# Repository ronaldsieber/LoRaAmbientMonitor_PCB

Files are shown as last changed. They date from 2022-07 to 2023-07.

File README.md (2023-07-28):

# LoRaAmbientMonitor_PCB

**KiCad project of a Printed Circuit Board (PCB) for the LoRa-AmbientMonitor, based on ESP32 with temperature, humidity, PIR motion and ambient light sensor, as well as car battery voltage measurement.**

The *LoRa-AmbientMonitor* is designed to monitor the ambient conditions inside a car garage and also to monitor the voltage of the car battery. The acquisited data are transmitted to a remote station (e.g. in the house) via LoRa radio (low-power/long-range radio protocol).

## Board Features

The *LoRa-AmbientMonitor* contains the following components:
- ESP32 LoRa Development Board with OLED display
- DHT22 (combined temperature and humidity sensor)
- ALS-PDIC243 (Ambient Light Sensor)
- HC-SR501 (PIR Motion Detector)
- 3 freely usable user LEDs
- 4-position DIP switch and 1 freely usable user button (CFG, SET)
- 12V input to measure car battery voltage

The measurement of the ambient brightness via the ALS-PDIC243 Ambient Light Sensor as well as measurement of the car battery voltage is realized via 2 inputs of the Adafruit_ADS1115 module (4 channel 15-bit ADC module).

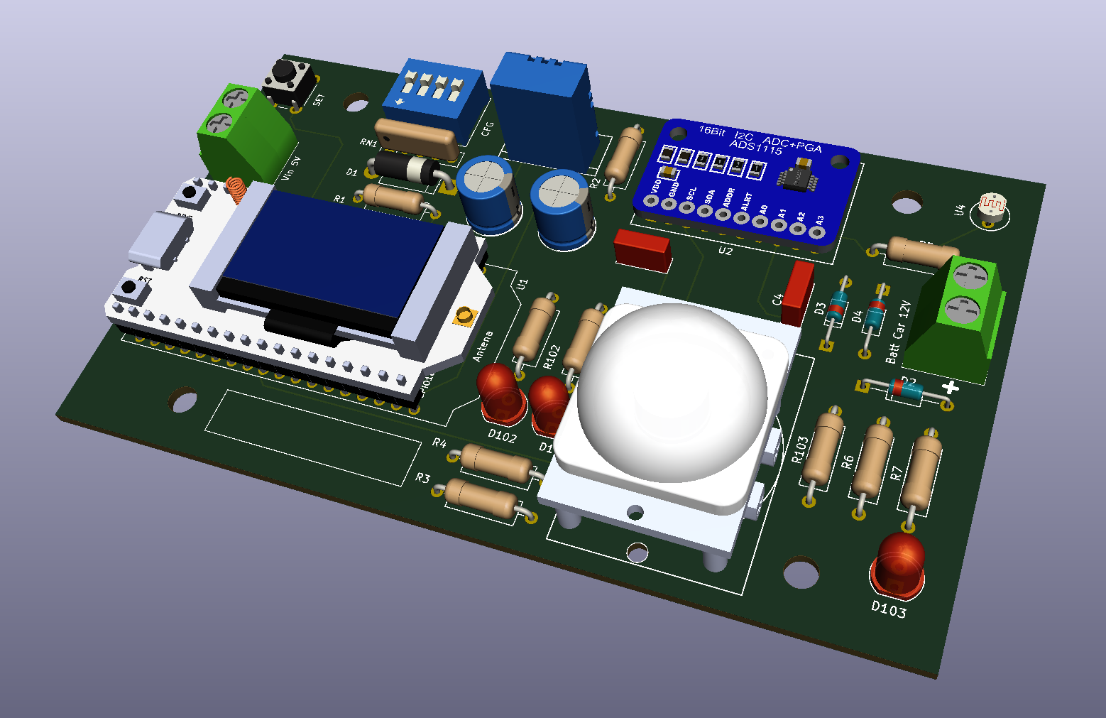
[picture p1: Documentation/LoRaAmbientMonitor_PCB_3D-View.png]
\[kicad_3d_model\]


## Board Description

The PCB of the *LoRa-AmbientMonitor* is a two-layer Printed Circuit Board (PCB), assembled on one side and only uses THT components (Through Hole Technology) that are very easy to solder. It can therefore be used very easily also by students and hobbyists.

The values of all components are specified in the [Schematic](Documentation/LoRaAmbientMonitor_PCB.sch.pdf). The [Silkscreen](Documentation/LoRaAmbientMonitor_PCB_Components.pdf) illustrates the placement of the components on the PCB.

The PCB size and the positions of the mounting holes allow installation in the plastic universal housing of 135 x 95 x 45 mm (article number 523117). Only the lower half-shell of the housing is used, so that the sensors (in particular the PIR motion detector HC-SR501 and the ambient light sensor ALS-PDIC243) can monitor the environment. Since the upper and lower half-shells are identical, the second half shell can be used for another *LoRa-AmbientMonitor*.

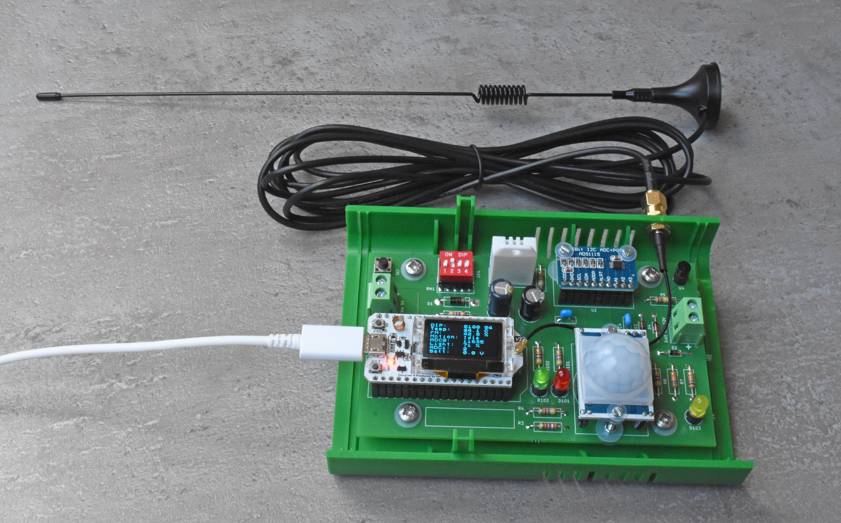
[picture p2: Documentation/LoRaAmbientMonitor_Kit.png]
\[LoRaAmbientMonitor_Kit\]


The user LEDs are connected to the GPIO of the ESP32 and can therefore be used freely in principle. However, the placement on the PCB was done in such a way that the following usage is favored:

 - LED D101, Red: Motion detected by PIR motion detector (HC-SR501).
 - LED D102, Green: Transmission of a LoRa data package
 - LED D103, yellow: connected car battery detected (e.g. Vin at J2 > 2V)

The 4-way DIP switch SW2 is also connected to the GPIO of the ESP32. It can be used for configuration settings at runtime. This makes it possible to program one and the same fixed firmware on several boards. Individual Node IDs can then be configured via the DIP switch. This individual Node IDs can be embedded in the LoRa data packets and thus enable the receiver to identify the correspondenting source module.

The User Button SW1 is also connected to the GPIO of the ESP32. It can be used freely by the application software and is suitable, among other things, as a starting condition for the [Bluetooth Configuration Framework](https://github.com/ronaldsieber/ESP32BleConfig).

The diodes D2, D3 and D4 serve as protection circuit for the ADC module ADS1115:
- D2: Reverse polarity protection for car battery measuring input
- D3: Overvoltage protection for car battery measuring input
- D4: Derivation of the car battery input voltage for a powerless ADS1115 (prevention of substrate conduction effects when a car battery is connected to a LoRa AmbientMonitor without power supply voltage)

## Power Supply

There are the following options for supplying power to the board:
- Via the USB port of the ESP32 LoRa Development Board (in this case, 'Pin2/5V' of the ESP32DevBoard acts as an output and supplies the rest of the circuit with it)
- Supply of 5...6VDC to connector J1 (in this case the board supplies the ESP32DevBoard and 'Pin2/5V' acts as an input)

## Commissioning

With the Arduino sketch from the [LoRaAmbientMonitor_IoCheck](https://github.com/ronaldsieber/LoRaAmbientMonitor_IoCheck) repository, all components of the board can be checked for correct function after assembly. The sketch is also a good starting point for new software projects based on this board.

## KiCad Schematic Symbols and Footprints

For the *LoRaAmbienteMonitor*, some schematic symbols and footprints have been newly created or modified. These are stored inside this repository in the [KiCad_Components/usrlib](KiCad_Components/usrlib) path.

The following KiCad library is also required for the combined temperature and humidity sensor DHT22:
https://github.com/skorokithakis/kicad-lib

## PCB Source of Supply

By searching in the Internet, several PCB manufacturers can be found who are able to directly import the KiCad layout file [LoRaAmbientMonitor_PCB.kicad_pcb](LoRaAmbientMonitor_PCB/LoRaAmbientMonitor_PCB.kicad_pcb). The PCBs with silkscreen (assembly printing) on the top are then sent by post after a few days.

## Practice Notes

On the PIR Motion Setector (U3, HC-SR501) are assembled larger/higher components such as trimmer potentiometers and electrolytic capacitors on its underside. Therefore, a 3-pin socket strip must be used on the PCB to ensure the required distance between the HC-SR501 and the PCB.

On the ESP32 LoRa Development Board (U1) there is a LiPo battery charger for 3.7V Lipo batteries is integrated. Due to the height of the JST 1.25mm battery connector on the underside of the board, the ESP32 LoRa Development Board cannot be soldered directly with its pin headers to the PCB of the *LoRaAmbienteMonitor*. Here, too, the required installation space can be created by using socket strips. Since the ESP32 LoRa Development Board has 18 pins per side, two 9-pin socket strips were used.

The 4-channel 15-bit ADC module (U2, Adafruit_ADS1115 module) is only equipped on its top side and can in principle be soldered directly to the PCB of the *LoRaAmbienteMonitor* with its pin headers. But here, too, the use of a 10-pin socket strip is a good idea, so that the module can be easily replaced if necessary.

## Software Projects for the LoRaAmbienteMonitor

- [LoRaAmbientMonitor_IoCheck](https://github.com/ronaldsieber/LoRaAmbientMonitor_IoCheck) - Checking of all components during commissioning and starting point for new software projects based on this board

- [LoraAmbientMonitor](https://github.com/ronaldsieber/LoraAmbientMonitor) - Complete software ecosystem for the *LoRaAmbienteMonitor* module, consisting of ESP32/Arduino firmware (transmitting side), Raspberry Pi gateway software (receiving and processing ambient data) and Windows/GUI commissioning tool.

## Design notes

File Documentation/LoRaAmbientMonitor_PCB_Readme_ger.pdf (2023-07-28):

Projekt: | https://github.com/ronaldsieber/LoRaAmbientMonitor_PCB
Lizenz: | MIT
Autor: | Ronald Sieber

## LoRaAmbientMonitor_PCB

KiCad Projekt des Printed Cuircit Boards (PCB) für den LoRa-AmbientMonitor auf ESP32-Basis mit Temperatur-, Luftfeuchtigkeits-, PIR-Bewegungs- und Umgebungslicht-Sensor, sowie Autobatterie-Spannungsmessung.

Der LoRa-AmbientMonitor ist dafür ausgelegt, die Umgebungsbedingungen innerhalb einer PKW-Garage zu monitoren und zusätzlich die Spannung der Autobatterie zu überwachen. Die erfassten Daten werden per LoRa-Funk (Low-Power/Long-Range Funkprotokoll) an eine entfernte Gegenstelle (z.B. im Wohnhaus) übertragen.

Board Features

Der LoRa-AmbientMonitor beinhalte folgende Komponenten:
- ESP32 LoRa Development Board mit OLED-Display
- DHT22 (kombinierter Temperatur- und Luftfeuchte-Sensor)
- ALS-PDIC243 (Ambient Light Sensor)
- HC-SR501 (PIR-Bewegungsmelder)
- 3 frei verwendbare User LEDs
- 4-fach DIP-Schalter und 1 frei verwendbare User Buttons (CFG, SET)
- 12V Eingang zur Messung der Autobatteriespannung

Die Messung der Umgebungshelligkeit über den ALS-PDIC243 Ambient Light Sensor sowie die Messung Autobatteriespannung erfolgen über 2 Eingänge des Adafruit_ADS1115 Moduls (4-fach 15Bit ADC-Modul).

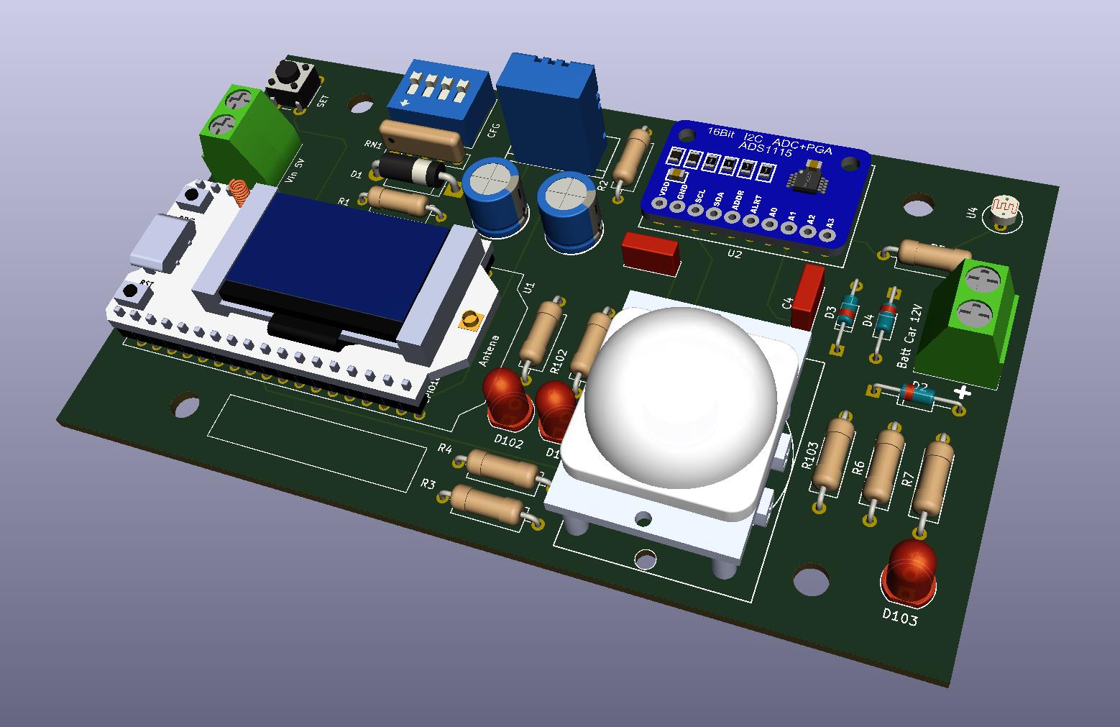
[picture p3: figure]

[kicad_3d_model]

Board Beschreibung

Die PCB des LoRa-AmbientMonitor ist eine zweilagige Leiterplatte, einseitig bestückt und verwendet nur sehr einfach zu lötende THT Bauteile (Through Hole Technology). Es kann somit sehr leicht auch von Schülern und Bastlern genutzt werden.

Die Werte aller Bauteile sind im <Schaltplan> spezifiziert. Die Platzierung der Bauteile auf der PCB veranschaulicht der <Bestückungsdruck>

Die PCB Größe und die Positionen der Mounting Holes erlauben den Einbau in das Kunststoff Universal Gehäuse von 135 x 95 x 45 mm (Artikel Nummer 523117). Vom Gehäuse wird dabei nur die Unterschale verwendet, so dass die Sensoren (insbesondere der PIR-Bewegungsmelder HC-SR501 und der Ambient Light Sensor ALS-PDIC243) die Umgebung überwachen können. Da Ober- und Unterschale identisch sind, kann die zweite Halbschale für einen weiteren LoRa-AmbientMonitor verwendet werden.

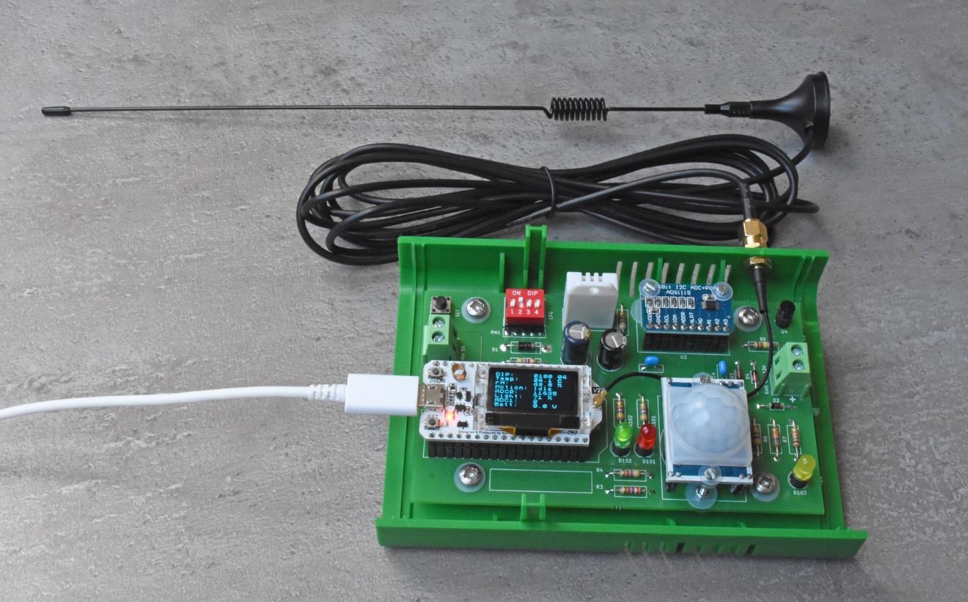
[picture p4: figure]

[LoRaAmbientMonitor_Kit]

Die User LEDs sind an GPIO des ESP32 angebunden und damit prinzipiell frei nutzbar. Die Platzierung auf der PCB erfolgte jedoch so, dass folgende Verwendung favorisiert wird:
- LED D101, Rot: Bewegung durch PIR-Bewegungsmelder (HC-SR501) erkannt
- LED D102, Grün: Übertragung eines LoRa Datenpaketes
- LED D103, Gelb: angeschlossene Autobatterie erkannt (z.B. Vin an J2 > 2V)

Der 4-fach DIP-Schalter SW2 ist ebenfalls an GPIO des ESP32 angebunden. Mit ihm können Konfigurationseinstellungen zur Laufzeit vorgenommen werden. So ist es möglich, eine feste Firmware auf mehrere Boards zu programmieren. Über den DIP-Schalter lassen sich dann individuelle Node-ID’s konfigurieren, die in die LoRa Datenpakte eingebettet werden und so dem Empfänger die Identifikation der jeweiligen Quelle ermöglichen.

Der User Button SW1 ist ebenso an GPIO des ESP32 angebunden. Er kann von der Applikations-Software frei verwendet werden und eignet sich u.a. als Startbedingung für das
<Bluetooth Configuration Framework>.

Die Dioden D2, D3 und D4 dienen als Schutzbeschaltung für den ADC Baustein ADS1115:
- D2: Verpolungsschutz für Autobatterie Messeingang
- D3: Überspannungsschutz für Autobatterie Messeingang
- D4: Ableitung der Autobatterie Eingangsspannung bei spannungslosem ADS1115 (Verhinderung von Substratleiteffekten, wenn eine Autobatterie an einen LoRa-AmbientMonitor ohne Versorgungsspannung angeschlossen ist)

Spannungsversorgung

Für die Spannungsversorgung des Boards gibt es folgende Möglichkeiten:
- über den USB-Anschluss des ESP32 LoRa Development Board (in diesem Fall wirkt ‘Pin2/5V‘ des ESP32DevBoards als Ausgang und versorgt die restliche Schaltung mit)
- Einspeisung von 5…6VDC an Konnektor J1 (in diesem Fall versorgt das Board das ESP32DevBoard und ‘Pin2/5V‘ wirkt als Eingang)

Inbetriebnahme

Mit dem Arduino Sketch des Repositories <LoRaAmbienteMonitor_IoCheck> können alle Komponenten des Boards nach dem Bestücken auf ihre korrekte Funktion überprüft werden. Außerdem ist der Sketch eine gute Ausgangsbasis für neue Software Projekte basierend auf diesem Board.

KiCad Schaltplan Symbole und Footprints

Für den LoRaAmbienteMonitor wurden einige Schaltplansymbole und Footprints neu erstellt bzw. modifiziert. Diese sind innerhalb dieses Repositories im Zweig <KiCad_Components/usrlib> abgelegt.

Für den kombinierter Temperatur- und Luftfeuchte-Sensor DHT22 ist außerdem folgende KiCad Library notwendig:

https://github.com/skorokithakis/kicad-lib

PCB Bezugsquelle

Bei einer Suche im Internet findet man leicht mehrere PCB Hersteller, die direkt das KiCad Layout File LoRaAmbientMonitor_PCB.kicad_pcb importieren können. Die PCBs erhält man dann mit Bestückungsdruck auf der Oberseite nach wenigen Tagen per Post zugeschickt.

Praxis Hinweise

Der PIR-Bewegungsmelder (U3, HC-SR501) ist auf seiner Unterseite mit höheren Bauteilen wie Trimmerpotentiometern und Elektrolytkondensatoren bestückt. Daher muss auf der PCB eine 3 polige Buchsenleiste verwendet werden, die den erforderlichen Abstand zur Platine des HC-SR501 gewährleistet.

Auf dem ESP32 LoRa Development Board (U1) ist ein LiPo Batterie Charger für 3.7V Lipo Akkus integriert. Bedingt durch die Bauhöhe des JST 1.25mm Akku-Anschlusses auf der Board-Unterseite kann das ESP32 LoRa Development Board nicht unmittelbar mit seinen Stiftleisten auf die PCB des LoRaAmbienteMonitor gelötet werden. Auch hier ist durch den Einsatz von Buchsenleisten der erforderliche Bauraum zu schaffen. Da das ESP32 LoRa Development Board pro Seite 18 Pins besitzt, wurden jeweils zwei 9 polige Buchsenleisten verwendet.

Das 4-fach 15Bit ADC-Modul (U2, Adafruit_ADS1115 Modul) ist nur auf seiner Oberseite bestückt und kann mit seinen Stiftleisten prinzipiell direkt auf die PCB des LoRaAmbienteMonitor gelötet werden. Aber auch hier bietet sich der Einsatz einer 10 poligen Buchsenleiste an, um das Modul im Bedarfsfall ggf. einfach tauschen zu können.

Software Projekte für den LoRaAmbienteMonitor

- <LoRaAmbienteMonitor_IoCheck> – Prüfen aller Komponenten während der Inbetriebnahme und Ausgangsbasis für neue Software Projekte basierend auf diesem Board
- <LoRaAmbienteMonitor> – Komplettes Software-Ökosystem für das LoRaAmbienteMonitor Modul, bestehend aus ESP32/Arduino-Firmware (Sendeseite), Raspberry Pi Gateway Software (Empfang und Verarbeitung der Umgebungsdaten) und Windows/GUI-Inbetriebnahme-Tool

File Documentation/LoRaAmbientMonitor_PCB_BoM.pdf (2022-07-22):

Komponente(n) | Wert | Beschreibung | Bestellnummer | Einzelpreis | Anzahl/PCB | Gesamtpreis
C1 | 100µF | Elko 100µF, Radial, D8.0mm | Reichelt.de: RAD LXZ 50/100 | 0,21 € | 1 | 0,21 €
C2, C4 | 1µF | Keramik-Kondensator 1 µF, Radial | Conrad.de: 453382 | 0,57 € | 2 | 1,14 €
C3 | 47µF | Elko 47µF, Radial, D8.0mm | Reichelt.de: EB-A 47U 63 | 0,23 € | 1 | 0,23 €
D1 | 1N 4001 | Diode, 50 V, 1 A, DO-41 | Reichelt.de: 1N 4001 | 0,02 € | 1 | 0,02 €
D2 | 1N 4148 | Diode, 100 V, 150 mA, DO-35 | Reichelt.de: 1N 4148 | 0,02 € | 1 | 0,02 €
D3 | ZF 4,7V (https://www.reichelt.de/zenerdiode-3-3-v-0-5-w-do-35-zf-3-3-p23126.html?&nbc=1) | Z-Diode, 4,7 V, 0,5 W, DO-35 | Reichelt.de: ZF 4,7 | 0,03 € | 1 | 0,03 €
D4 | BAT42 | Schottkydiode, 30 V, 0,2 A, DO-35 | Reichelt.de: BAT 42 | 0,05 € | 1 | 0,05 €
D101 | LED rot | LED 5mm (Rot) | Reichelt.de: LED 5MM RT | 0,07 € | 1 | 0,07 €
D102 | LED grün | LED 5mm (Grün) | Reichelt.de: LED 5MM GN | 0,07 € | 1 | 0,07 €
D103 | LED gelb | LED 5mm (Gelb) | Reichelt.de: LED 5MM GE | 0,07 € | 1 | 0,07 €
R1, R2, R4 | 4k7 | Widerstand, 4,7k | Reichelt.de: 1/4W 4,7K | 0,03 € | 3 | 0,09 €
R3 | 2k7 | Widerstand, 2,7k | Reichelt.de: 1/4W 2,7K | 0,03 € | 1 | 0,03 €
R5 | 100k | Widerstand, 100k | Reichelt.de: 1/4W 100K | 0,03 € | 1 | 0,03 €
R6 | 68k | Widerstand, 68k | Reichelt.de: 1/4W 68K | 0,03 € | 1 | 0,03 €
R7 | 18k | Widerstand, 18k | Reichelt.de: 1/4W 18K | 0,03 € | 1 | 0,03 €
R101, R102, R103 | 470R | Widerstand, 470R | Reichelt.de: 1/4W 470 | 0,03 € | 3 | 0,09 €
RN1 | 4x4k7 | Widerstandsnetzwerk, 4,7k, Stern | Reichelt.de: SIL 5-4 4,7K | 0,06 € | 1 | 0,06 €
SW1 | BLE_CFG | Kurzhubtaster 6x6mm, Höhe 5,0mm | Reichelt.de: TASTER 9302 | 0,16 € | 1 | 0,16 €
SW2 | SW_DIP_x04 | Dip-Schalter, liegend, 4-polig | Reichelt.de: NT 04 | 0,22 € | 1 | 0,22 €
TH1 | DHT22 | Temperatur- & Feuchtigkeitssensor | Reichelt.de: DEBO DHT 22 | 6,80 € | 1 | 6,80 €
U1 | Heltec_WiFi_LoRa_V2 | Heltec_WiFi_LoRa_V2 | { Amazon, SX1276 V2 Lora ESP32} | 29,99 € | 1 | 29,99 €
U2 | Adafruit_ADS1115 | Adafruit_ADS1115 | { Amazon, AZDelivery 3 x ADS1115 } | 3,93 € | 1 | 3,93 €
U3 | HC-SR501 | Infrarot Bewegungsmelder, PIR | Reichelt.de: RPI HC-SR501 | 2,30 € | 1 | 2,30 €
U4 | ALS-PDIC243 | Ambient Light Sensor | Reichelt.de: EVL ALS-PDIC243 | 0,43 € | 1 | 0,43 €
J1, J2 | | Schraubklemme, 2-pol, RM 5 mm | Reichelt.de: CTB0102-2 | 0,32 € | 2 | 0,64 €
Stiftleiste | { für A/B Heltec } | Stiftleiste 18 polig (2 x 9 polig) | Reichelt.de: FIS BL1 09 Z | 0,60 € | 4 | 2,40 €
Stiftleiste | { für ADS1115 } | Stiftleiste 10 polig | Reichelt.de: FIS BL1 10 Z | 0,70 € | 1 | 0,70 €
Stiftleiste | { für HC-SR501 } | Stiftleiste 3 polig | Reichelt.de: MPE 094-1-003 | 0,16 € | 1 | 0,16 €
| | | | | | 50,00 €

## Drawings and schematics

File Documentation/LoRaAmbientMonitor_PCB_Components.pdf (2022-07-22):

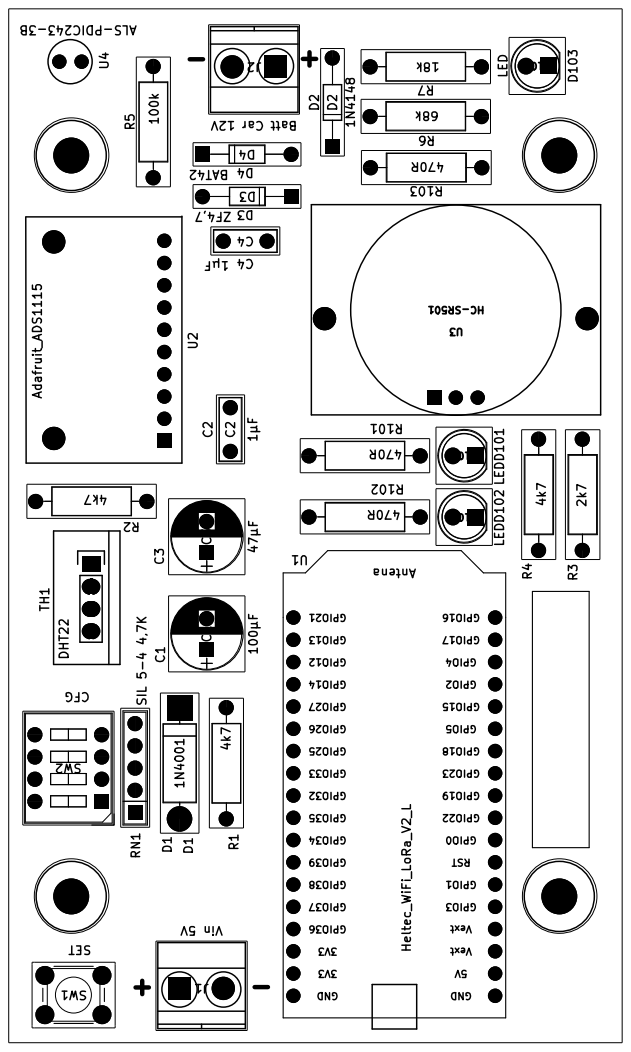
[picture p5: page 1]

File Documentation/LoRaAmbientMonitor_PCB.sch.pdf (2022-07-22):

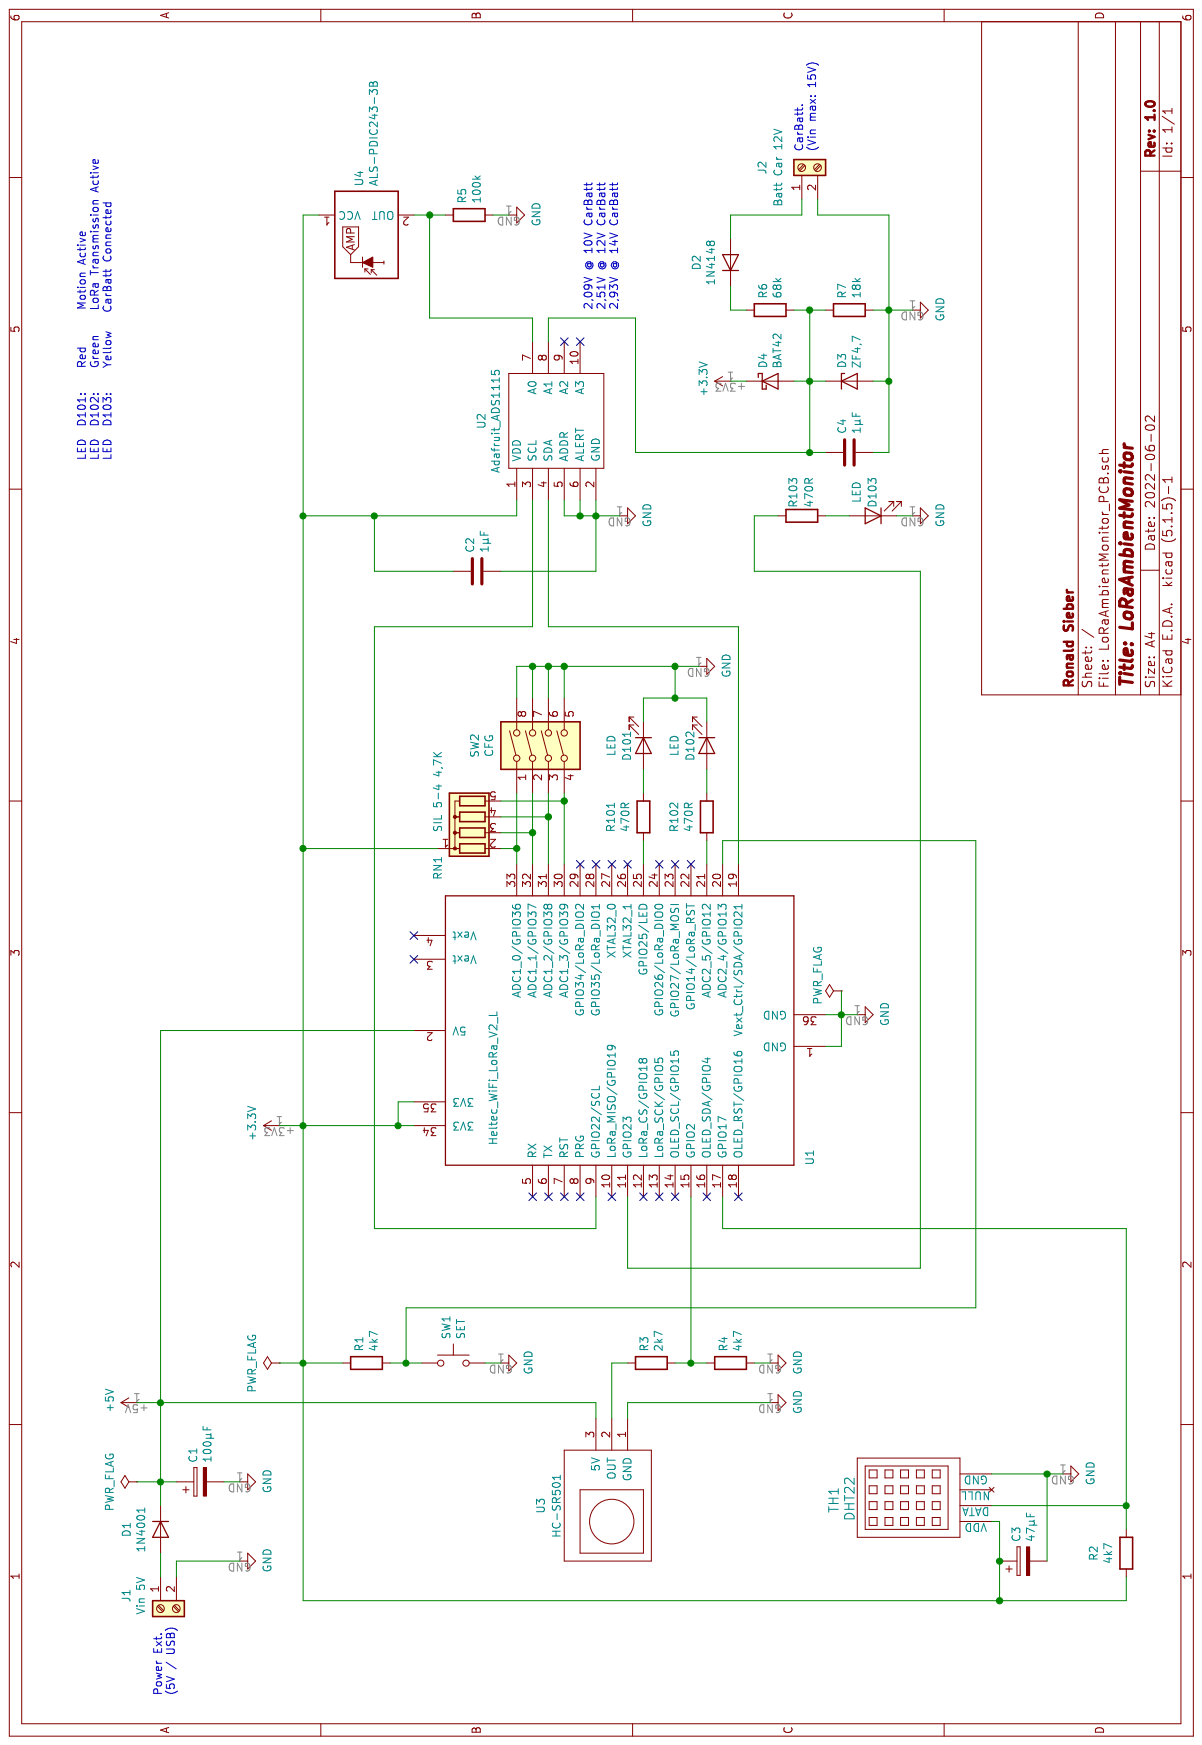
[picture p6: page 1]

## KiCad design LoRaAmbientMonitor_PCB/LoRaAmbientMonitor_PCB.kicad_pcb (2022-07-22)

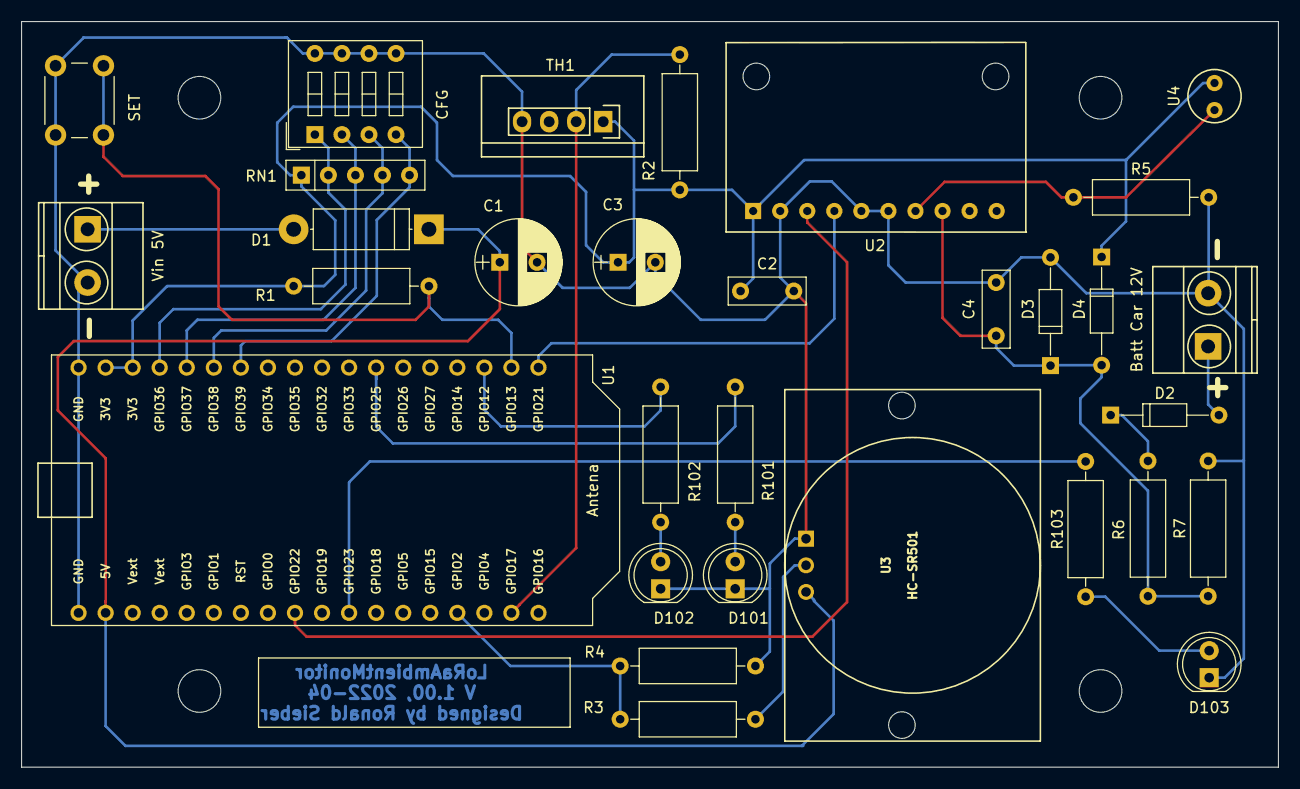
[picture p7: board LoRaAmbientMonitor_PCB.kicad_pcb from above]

Board: 2 copper layers, 118.0 x 70.0 mm, 31 parts (0 on the bottom side), 24 nets.

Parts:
C1: 100µF; CP_Radial_D8.0mm_P3.50mm
C2, C4: 1µF; C_Rect_L7.2mm_W2.5mm_P5.00mm_FKS2_FKP2_MKS2_MKP2
C3: 47µF; CP_Radial_D8.0mm_P3.50mm
D1: 1N4001; D_5W_P12.70mm_Horizontal
D2: 1N4148; D_DO-35_SOD27_P10.16mm_Horizontal
D3: ZF4,7; D_DO-35_SOD27_P10.16mm_Horizontal
D4: BAT42; D_DO-35_SOD27_P10.16mm_Horizontal
D101, D102, D103: LED; LED_D5.0mm
J1: Vin 5V; TerminalBlock_Phoenix_MKDS1.5-2pol
J2: Batt Car 12V; TerminalBlock_Phoenix_MKDS1.5-2pol
R1, R2, R4: 4k7; R_Axial_DIN0309_L9.0mm_D3.2mm_P12.70mm_Horizontal
R3: 2k7; R_Axial_DIN0309_L9.0mm_D3.2mm_P12.70mm_Horizontal
R5: 100k; R_Axial_DIN0309_L9.0mm_D3.2mm_P12.70mm_Horizontal
R6: 68k; R_Axial_DIN0309_L9.0mm_D3.2mm_P12.70mm_Horizontal
R7: 18k; R_Axial_DIN0309_L9.0mm_D3.2mm_P12.70mm_Horizontal
R101, R102, R103: 470R; R_Axial_DIN0309_L9.0mm_D3.2mm_P12.70mm_Horizontal
RN1: SIL 5-4 4,7K; R_Array_SIP5
SW1: SET; SW_PUSH_6mm_h5mm
SW2: CFG; SW_DIP_x4_W7.62mm_Slide
TH1: DHT22; DHT22_Temperature_Humidity
U1: Heltec_WiFi_LoRa_V2_L; Heltec_WiFi_LoRa_V2
U2: Adafruit_ADS1115
U3: HC-SR501
U4: ALS-PDIC243

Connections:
+3V3: C2.1, C3.1, D4.1, R1.1, R2.2, RN1.1, TH1.1, U1.34, U1.35, U2.1, U4.1
+5V: C1.1, D1.1, U1.2, U3.3
GND: C1.2, C2.2, C3.2, C4.2, D3.2, D101.1, D102.1, D103.1, J1.2, J2.2, R4.2, R5.2, R7.2, SW1.2, SW2.5, SW2.6, SW2.7, SW2.8, TH1.4, U1.1, U1.36, U2.2, U2.5, U2.6, U3.1
unnamed: C4.1, D3.1, D4.2, R6.2, R7.1, U2.8
unnamed: D1.2, J1.1
unnamed: D2.1, R6.1
unnamed: D2.2, J2.1
unnamed: D101.2, R101.1
unnamed: D102.2, R102.1
unnamed: D103.2, R103.1
unnamed: R1.2, SW1.1, U1.20
unnamed: R2.1, TH1.2, U1.17
unnamed: R3.1, U3.2
unnamed: R3.2, R4.1, U1.15
unnamed: R5.1, U2.7, U4.2
unnamed: R101.2, U1.25
unnamed: R102.2, U1.21
unnamed: R103.2, U1.11
unnamed: RN1.2, SW2.1, U1.33
unnamed: RN1.3, SW2.2, U1.32
unnamed: RN1.4, SW2.3, U1.31
unnamed: RN1.5, SW2.4, U1.30
unnamed: U1.9, U2.3
unnamed: U1.19, U2.4
